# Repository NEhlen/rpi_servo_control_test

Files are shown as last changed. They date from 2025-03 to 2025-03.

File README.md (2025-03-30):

# Servo-Controlled Eye

This is a python project for a servo controlled eye with a USB webcam. The project is meant to be run on a raspberry pi 4B (but will probably work on any raspberry pi).

The project uses the huggingface transformers library with [clipseg](https://huggingface.co/docs/transformers/model_doc/clipseg) to be able to focus the eye on any object inside its vision cone named via text input.
It can also do face tracking so the eye follows the user as he moves around.
The eye is based on a heavily modified version of the [animatronic eye on printables](https://www.printables.com/model/278169-animatronic-eye). It uses two DPower AS-107BB nano servo motors.

To run the project please run `src/look_around_servokit.py`.

Video:
data/video/demo.mp4

## Build-Details

### Schematics

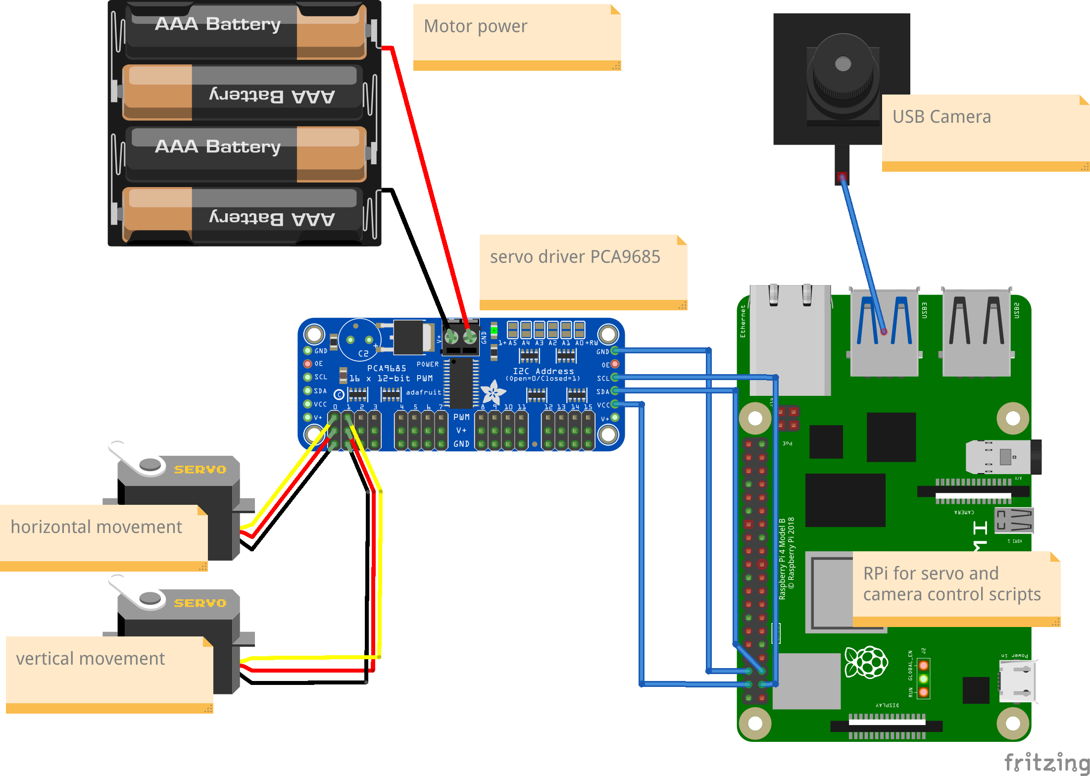
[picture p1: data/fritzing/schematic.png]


Fritzing Sketch under `data/fritzing/sketch.fzz`

### Parts and Tools List

* 2x AS-107BB Servo Motors
* armature wire
* Raspberry Pi 4B
* USB webcam (ideally with wide angle view)
* 5V DC power supply/ 4 AA-Batteries + Battery Holder
* Adafruit PCA9685 16x servo driver

Tools:
3D printer, precision mechanics screwdriver and screws, sticky tape

### Build Steps
1. 3D print the eye and socket-connector from the printables link
2. 3D print the servo holder and stand from the `data/blender` folder
3. Insert USB camera in stand (might need sticky tape), screw servos into holder and screw eye socket connector to the servo-holder
4. wire up the servos and the 5V power supply to the servo driver
5. wire up usb cam and servo driver to raspberry pi
6. bend armature wires and connect eye with servo motors (might need to enlargen the holes in the servo arms depending on armature wire thickness)

### Images

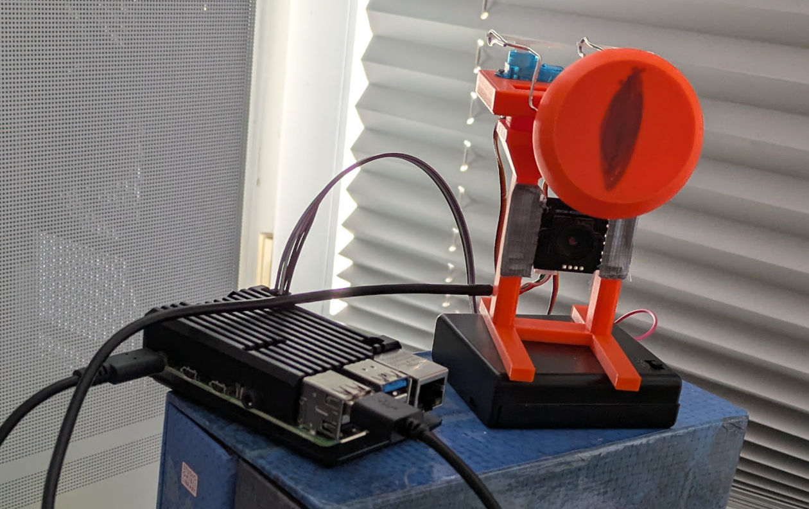
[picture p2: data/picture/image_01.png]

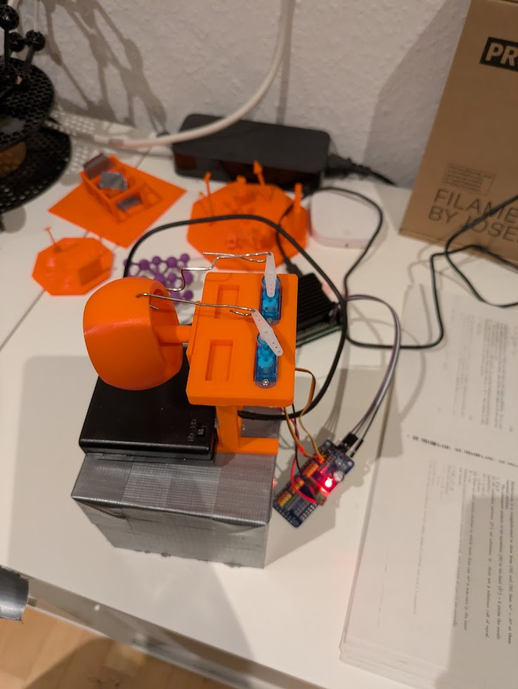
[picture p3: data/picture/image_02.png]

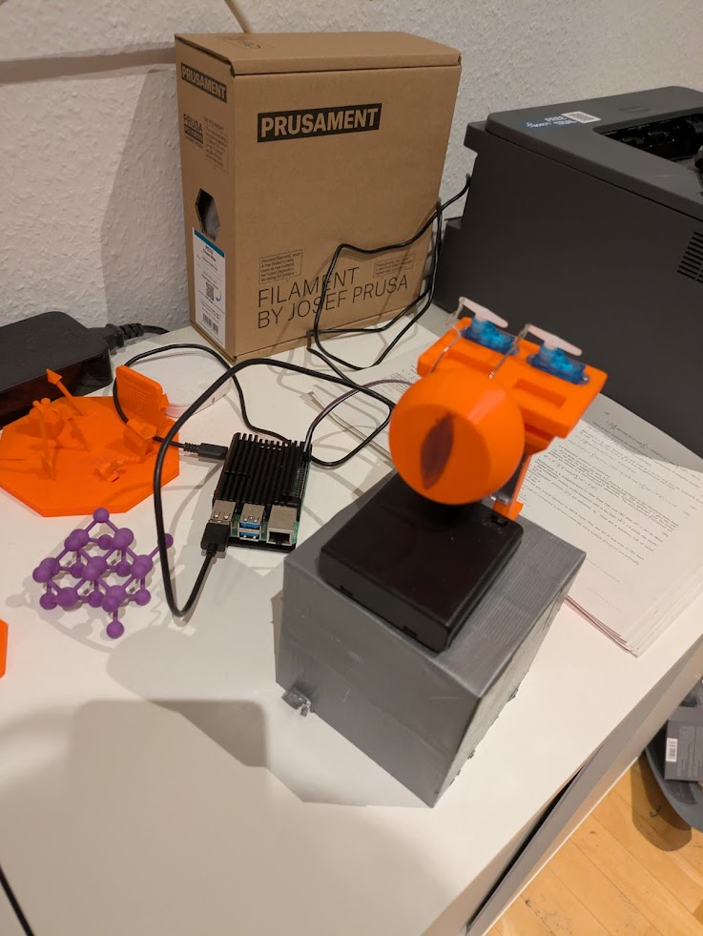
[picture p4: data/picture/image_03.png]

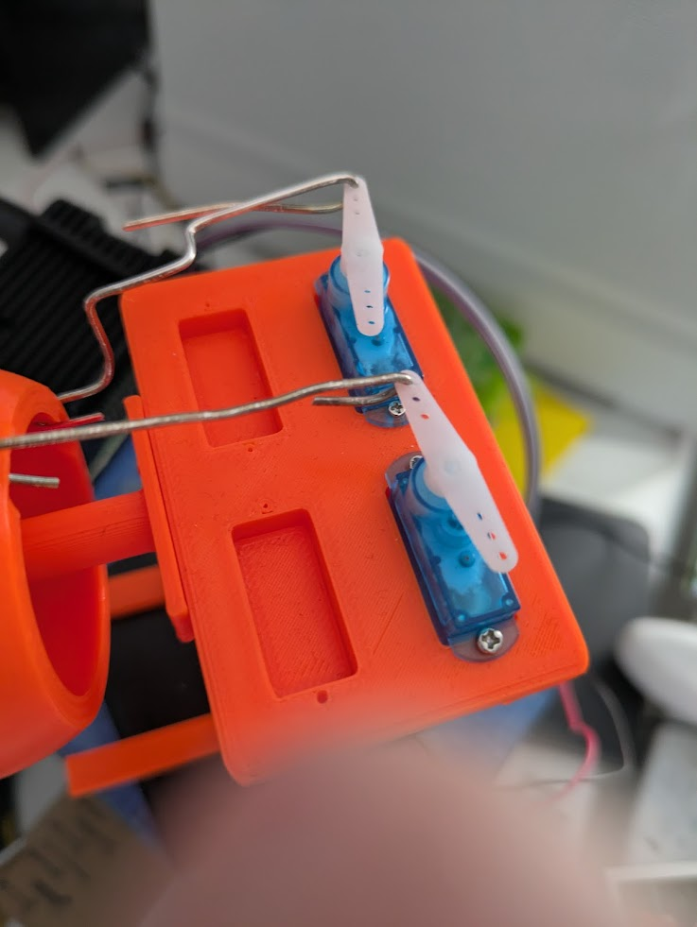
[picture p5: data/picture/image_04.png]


## Software Details

### Clipseg
[clipseg](https://huggingface.co/docs/transformers/model_doc/clipseg) is used for determining relevant features in the webcam feed given a text input.
The feature with the highest logits is selected as the spot to focus the eye on.
Currentyl the logic to move the eye is very simple and just uses a very rough localization of the center of gravity of the focus point inside one of 9 parts of the image to determine where the eye should move.
Clipseg is small enough that it can run on the raspberry pi directly within a few seconds when applied to small images. For speedup, an api based approach could be used in the future.

Example:  
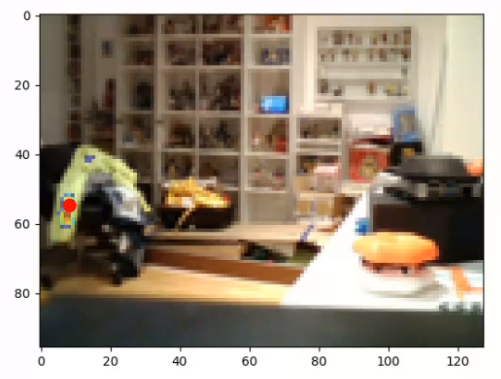
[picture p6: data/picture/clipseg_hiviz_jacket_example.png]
  
Clipseg feature for text entry "hi-viz jacket"

### Face tracking

The project uses the [face tracking via haar cascades provided by opencv](https://docs.opencv.org/4.x/d2/d99/tutorial_js_face_detection.html). It's using the nonlinear [Fermi function](https://en.wikipedia.org/wiki/Fermi%E2%80%93Dirac_statistics)/[logistic function](https://en.wikipedia.org/wiki/Logistic_function) to translate the center point of the face in pixel coordinates to the angles of the eye/servos.

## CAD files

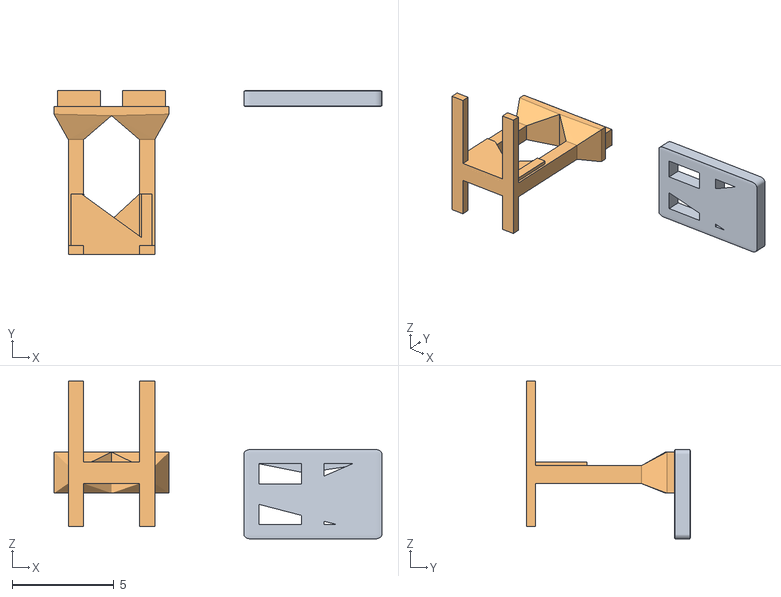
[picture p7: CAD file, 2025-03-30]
data/blender/eye_servo_holder_and_stand.obj
16.1 x 8.08 x 7.77

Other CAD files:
data/blender/eye_servo_holder_2.blend

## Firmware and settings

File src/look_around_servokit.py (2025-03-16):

# Set up libraries and overall settings
from time import sleep  # Imports sleep (aka wait or pause) into the program
import numpy as np
from adafruit_servokit import ServoKit, _Servo
import threading
from collections import deque

kit = ServoKit(channels=16)

horizontal_min = 45
horizontal_max = 120
horizontal_center = 82

vertical_min = 60
vertical_max = 140
vertical_center = 100

ph = kit.servo[0]
pv = kit.servo[1]

ph.angle = 90
pv.angle = 90

ph.angle = None
pv.angle = None


def limit_angle(angle: float, direction="horizontal"):
    if direction == "vertical":
        angle = max(angle, vertical_min)
        angle = min(angle, vertical_max)
    else:
        angle = max(angle, horizontal_min)
        angle = min(angle, horizontal_max)
    return angle


def angle_interpolation2d(
    start_angle_hor: float,
    end_angle_hor: float,
    ph: _Servo,
    start_angle_ver: float,
    end_angle_ver: float,
    pv: _Servo,
    steps: int = 50,
):
    for i in np.linspace(0, 1, steps):
        interpolated_angle_hor = (
            start_angle_hor
            + (end_angle_hor - start_angle_hor) * (1 - np.cos(i * np.pi)) / 2
        )
        interpolated_angle_ver = (
            start_angle_ver
            + (end_angle_ver - start_angle_ver) * (1 - np.cos(i * np.pi)) / 2
        )
        ph.angle = limit_angle(interpolated_angle_hor, "horizontal")
        pv.angle = limit_angle(interpolated_angle_ver, "vertical")
        sleep(0.01)


def look_up(cur_angle_hor, cur_angle_ver):
    angle_interpolation2d(
        cur_angle_hor, horizontal_center, ph, cur_angle_ver, vertical_min, pv
    )
    return horizontal_center, vertical_min


def look_down(cur_angle_hor, cur_angle_ver):
    angle_interpolation2d(
        cur_angle_hor, horizontal_center, ph, cur_angle_ver, vertical_max, pv
    )
    return horizontal_center, vertical_max


def look_right(cur_angle_hor, cur_angle_ver):
    angle_interpolation2d(
        cur_angle_hor, horizontal_min, ph, cur_angle_ver, vertical_center, pv
    )
    return horizontal_min, vertical_center


def look_left(cur_angle_hor, cur_angle_ver):
    angle_interpolation2d(
        cur_angle_hor, horizontal_max, ph, cur_angle_ver, vertical_center, pv
    )
    return horizontal_max, vertical_center


def look_center(cur_angle_hor, cur_angle_ver):
    angle_interpolation2d(
        cur_angle_hor, horizontal_center, ph, cur_angle_ver, vertical_center, pv
    )
    return horizontal_center, vertical_center


def look_up_left(cur_angle_hor, cur_angle_ver):
    angle_interpolation2d(
        cur_angle_hor, horizontal_max, ph, cur_angle_ver, vertical_min, pv
    )
    return horizontal_max, vertical_min


def look_up_right(cur_angle_hor, cur_angle_ver):
    angle_interpolation2d(
        cur_angle_hor, horizontal_min, ph, cur_angle_ver, vertical_min, pv
    )
    return horizontal_min, vertical_min


def look_down_left(cur_angle_hor, cur_angle_ver):
    angle_interpolation2d(
        cur_angle_hor, horizontal_max, ph, cur_angle_ver, vertical_max, pv
    )
    return horizontal_max, vertical_max


def look_down_right(cur_angle_hor, cur_angle_ver):
    angle_interpolation2d(
        cur_angle_hor, horizontal_min, ph, cur_angle_ver, vertical_max, pv
    )
    return horizontal_min, vertical_max


def clip_mode():
    from interpret_webcam import get_look_direction

    cah, cav = horizontal_center, vertical_center
    look_for = ""
    while True:
        look_for = input("What do you want to look for? ")
        if look_for == "exit":
            break
        horizontal, vertical = get_look_direction(look_for)
        print("looking", horizontal, vertical)
        if horizontal == "right":
            if vertical == "up":
                cah, cav = look_up_right(cah, cav)
            elif vertical == "down":
                cah, cav = look_down_right(cah, cav)
            else:
                cah, cav = look_right(cah, cav)

        elif horizontal == "left":
            if vertical == "up":
                cah, cav = look_up_left(cah, cav)
            elif vertical == "down":
                cah, cav = look_down_left(cah, cav)
            else:
                cah, cav = look_left(cah, cav)

        else:
            if vertical == "up":
                cah, cav = look_up(cah, cav)
            elif vertical == "down":
                cah, cav = look_down(cah, cav)
            else:
                cah, cav = look_center(cah, cav)

        ph.angle = None
        pv.angle = None


target_cah = horizontal_center
target_cav = vertical_center


def bezier_interpolation(p0, p1, p2, p3, t):
    """Calculate the position on a cubic Bezier curve."""
    return (
        (1 - t) ** 3 * p0
        + 3 * (1 - t) ** 2 * t * p1
        + 3 * (1 - t) * t**2 * p2
        + t**3 * p3
    )


def face_detection_mode_smooth(plot: bool = False):
    from face_tracking import detect_face

    global target_cah, target_cav
    position_queue = deque(
        maxlen=1
    )  # Queue to store the last 4 positions for Bezier curve

    def detect_faces():
        while True:
            px, py = detect_face(plot)
            if px is not None and py is not None:
                px = 1 / (1 + np.exp(-10 * (px - 0.5)))
                py = 1 / (1 + np.exp(-15 * (py - 0.3)))
                pxa = (1 - px) * (horizontal_max - horizontal_min) + horizontal_min
                pya = py * (vertical_max - vertical_min) + vertical_min
                if len(position_queue) == 1:
                    position_queue.popleft()
                position_queue.append((pxa, pya))

    def move_servos():
        global target_cah, target_cav
        cah, cav = horizontal_center, vertical_center
        while True:
            if len(position_queue) >= 1:
                (p0,) = position_queue
                # for t in np.linspace(0, 1, 40):
                #    target_cah = bezier_interpolation(cah, p0[0], p1[0], p2[0], t)
                #    target_cav = bezier_interpolation(cav, p0[1], p1[1], p2[1], t)
                target_cah = cah + 0.005 * (p0[0] - cah)
                target_cav = cav + 0.005 * (p0[1] - cav)
                ph.angle = limit_angle(target_cah, "horizontal")
                pv.angle = limit_angle(target_cav, "vertical")
                cah = target_cah
                cav = target_cav
                # sleep(0.01)
                # position_queue.popleft()  # Remove the oldest position after interpolation
            else:
                sleep(0.01)

    # Start the face detection thread
    face_detection_thread = threading.Thread(target=detect_faces)
    face_detection_thread.daemon = True
    face_detection_thread.start()

    # Start the servo movement thread
    move_servos_thread = threading.Thread(target=move_servos)
    move_servos_thread.daemon = True
    move_servos_thread.start()

    # Keep the main thread alive
    while True:
        sleep(1)


def face_detection_mode(plot: bool = False):
    from face_tracking import detect_face

    cah, cav = horizontal_center, vertical_center
    while True:
        px, py = detect_face(plot)

        if px is not None and py is not None:
            px = 1 / (1 + np.exp(-10 * (px - 0.5)))
            py = 1 / (1 + np.exp(-15 * (py - 0.3)))
            print(px, py)
            pxa = (1 - px) * (horizontal_max - horizontal_min) + horizontal_min
            pya = py * (vertical_max - vertical_min) + vertical_min
            print(pxa, pya)
            angle_interpolation2d(cah, pxa, ph, cav, pya, pv, steps=20)
            cah = pxa
            cav = pya

        ph.angle = None
        pv.angle = None


def random_movement_mode():
    cah, cav = horizontal_center, vertical_center
    while True:
        new_cah = np.random.randint(horizontal_min, horizontal_max)
        new_cav = np.random.randint(vertical_min, vertical_max)
        angle_interpolation2d(
            cah,
            new_cah,
            ph,
            cav,
            new_cav,
            pv,
            steps=np.random.randint(40, 100),
        )
        cah = new_cah
        cav = new_cav
        ph.angle = None
        pv.angle = None
        sleep(np.random.random() * 0.5)


if __name__ == "__main__":
    try:
        mode = input("Choose Mode [CLIP, FACE, RANDOM] ")
        if mode.lower() == "clip":
            clip_mode()

        elif mode.lower() == "face":
            face_detection_mode_smooth(plot=False)

        elif mode.lower() == "random":
            random_movement_mode()

        else:
            print("Invalid mode")
    except KeyboardInterrupt:
        pass
    finally:
        # Clean up everything
        ph.angle = None  # At the end of the program, stop the PWM
        pv.angle = None

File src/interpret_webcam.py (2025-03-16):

import cv2
from PIL import Image
from transformers import CLIPSegProcessor, CLIPSegForImageSegmentation
from PIL import Image
import torch
import numpy as np
import matplotlib.pyplot as plt
import time


def get_image_from_webcam():
    cap = cv2.VideoCapture(0)

    # ret, frame = cap.read()
    # time.sleep(0.5)
    ret, frame = cap.read()
    cap.release()

    if ret:
        frame_rgb = cv2.cvtColor(frame, cv2.COLOR_BGR2RGB)
        image = Image.fromarray(frame_rgb)
        return image
    else:
        print("Error: Could not capture image from webcam.")
        return None


def get_look_direction(obect_to_look_at: str):
    image = get_image_from_webcam()
    if image is None:
        return None

    # Use the image to determine the look direction
    processor = CLIPSegProcessor.from_pretrained("CIDAS/clipseg-rd64-refined")
    model = CLIPSegForImageSegmentation.from_pretrained(
        "CIDAS/clipseg-rd64-refined"
    ).cpu()

    prompt = obect_to_look_at
    threshold = 0.9

    image.thumbnail((128, 128))
    inputs = processor(text=prompt, images=image, return_tensors="pt")
    inputs = {k: v.cpu() for k, v in inputs.items()}
    with torch.no_grad():
        outputs = model(**inputs)
        preds = outputs.logits
    pred = torch.sigmoid(preds)
    mat = pred.squeeze().cpu().numpy()
    mask = Image.fromarray(np.uint8(mat * 255), "L")
    mask = mask.convert("RGB")
    mask = mask.resize(image.size)

    mask = np.array(mask)[:, :, 0]

    # normalize the mask
    mask_min = mask.min()
    mask_max = mask.max()
    mask = (mask - mask_min) / (mask_max - mask_min)

    # threshold the mask
    bmask = mask > threshold
    # zero out values below the threshold
    mask[~bmask] = 0

    # determine from which function to choose in order to look at the object:
    # look right, look left, look up, look down, look center
    # look right and up, look right and down
    # look left and up, look left and down
    py, px = np.where(bmask)

    fig, ax = plt.subplots()
    ax.imshow(image)
    mask[~bmask] = np.nan
    ax.imshow(mask, alpha=0.5, cmap="jet")

    ax.scatter(np.mean(px), np.mean(py), c="r", s=100)

    fig.savefig("test.png")
    plt.close()
    hor = ""
    ver = ""
    if len(px) == 0:
        hor = "center"
        ver = "center"
    elif np.mean(px) < image.size[0] / 3:
        hor = "left"
    elif np.mean(px) > 2 * image.size[0] / 3:
        hor = "right"
    else:
        hor = "center"

    if np.mean(py) < image.size[1] / 3:
        ver = "up"
    elif np.mean(py) > 2 * image.size[1] / 3:
        ver = "down"
    else:
        ver = "center"

    return hor, ver


if __name__ == "__main__":
    get_look_direction("human")

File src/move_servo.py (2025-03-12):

# Set up libraries and overall settings
import RPi.GPIO as GPIO  # Imports the standard Raspberry Pi GPIO library
from time import sleep  # Imports sleep (aka wait or pause) into the program

GPIO.setmode(GPIO.BOARD)  # Sets the pin numbering system to use the physical layout

# Set up pin 11 for PWM
GPIO.setup(11, GPIO.OUT)  # Sets up pin 11 to an output (instead of an input)
GPIO.setup(12, GPIO.OUT)  # Sets up pin 11 to an output (instead of an input)
p = GPIO.PWM(11, 50)  # Sets up pin 11 as a PWM pin
p2 = GPIO.PWM(12, 50)  # Sets up pin 11 as a PWM pin
p.start(0)  # Starts running PWM on the pin and sets it to 0
p2.start(0)
# Move the servo back and forth
p.ChangeDutyCycle(5)  # Changes the pulse width to 2 (so moves the servo)
sleep(1)  # Wait 1 second
p.ChangeDutyCycle(9)  # Changes the pulse width to 12  (so moves the servo)
sleep(1)
p.ChangeDutyCycle(7)  # Changes the pulse width to 7  (so moves the servo)
sleep(1)
p2.ChangeDutyCycle(5)  # Changes the pulse width to 2 (so moves the servo)
sleep(1)  # Wait 1 second
p2.ChangeDutyCycle(9)  # Changes the pulse width to 7  (so moves the servo)
sleep(1)
p2.ChangeDutyCycle(7)  # Changes the pulse width to 7  (so moves the servo)
sleep(1)

# Clean up everything
p.stop()  # At the end of the program, stop the PWM
p2.stop()
GPIO.cleanup()  # Resets the GPIO pins back to defaults

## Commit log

2025-03-12 camera local deployment
2025-03-14 added propper servo
2025-03-16 added camera initiation
2025-03-30 added documentation
    [eye_servo_holder_2.blend, eye_servo_holder_and_stand.obj, sketch.fzz]
